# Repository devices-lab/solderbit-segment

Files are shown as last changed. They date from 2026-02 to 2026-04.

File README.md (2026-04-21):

# solder:bit Segment

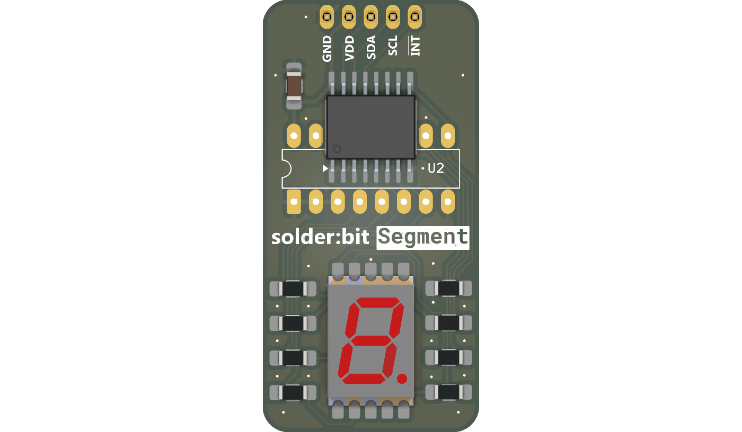
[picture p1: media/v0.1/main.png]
solder:bit Segment A render of the latest solder:bit Segment


The solder:bit Segment is a kit for learning to solder with surface-mount (SMT) components. When assembled, the device can display a single digit on a 7-segment display. It works with any microcontroller that communicates over the [I²C protocol](https://en.wikipedia.org/wiki/I2C).

This soldering kit is designed to accommodate a wide range of soldering abilities. The I/O expander is available in two different packages. The PCF8574AT in the **SO-16** package is smaller and more challenging to solder, while the PCF8574N in the **DIP-16** package is larger and through-hole (THT), making it more accessible for novices. The same printed circuit board (PCB) has footprints for both packages, and you choose which component to solder based on your ability. The device functions identically regardless of which package you use. Note that once you have soldered one package, the footprint for the other will no longer be accessible.

| I/O expander in an SO-16 package (SMT) | I/O expander in a DIP-16 package (THT) |
| --- | --- |
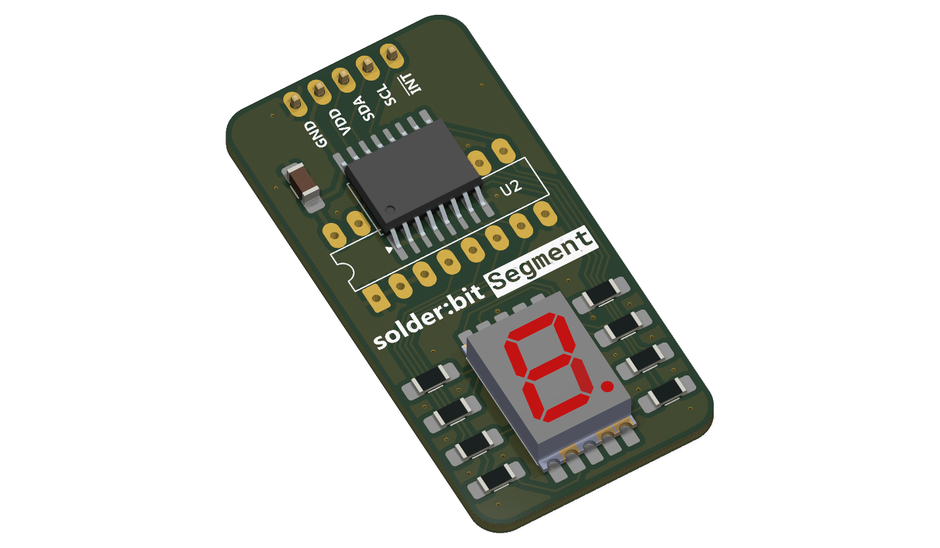
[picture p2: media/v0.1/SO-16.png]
SMT
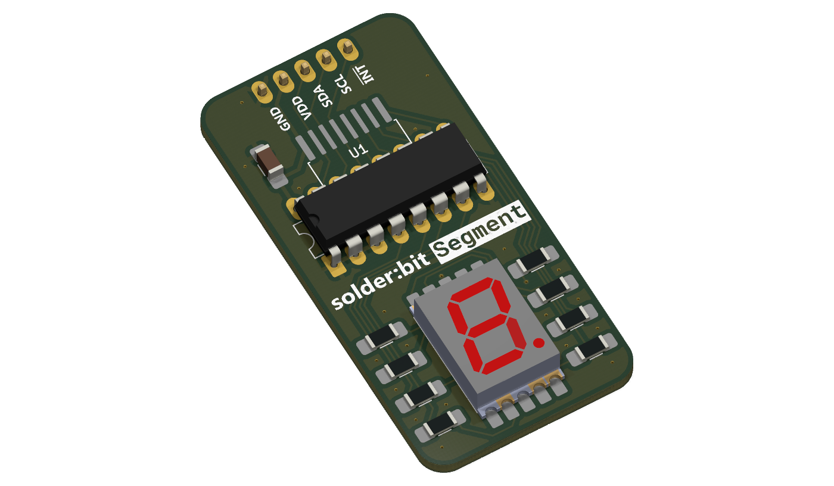
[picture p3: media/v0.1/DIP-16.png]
THT
|  |  |

## Getting started

> [!WARNING]
> This device is a research prototype and is provided as-is. Use it at your own risk. The authors take no responsibility for any damage, injury, or loss arising from its use.

To get started, you will need the following:

1. The printed circuit boards (PCBs), which you will need to have manufactured.
2. All components listed in the bill of materials (BOM).
3. A microcontroller development board, like the BBC micro:bit.
4. All equipment and materials required for soldering.

### Printed circuit boards (PCBs)

The solder:bit Segment fabrication files are open source, so you can order the PCBs yourself!

To fabricate the PCB, use the files in the [gerbers-v0.1](/fabrication/gerbers-v0.1/) folder.

### Components

> [!NOTE]
> Most of these components are sourced from [Onecall (Farnell/CPC)](https://onecall.farnell.com/), but as they are fairly common components, alternatives can be found from other suppliers such as LCSC, DigiKey, and others.

| Reference | Quantity | Part | Package | Onecall order code |
| --- | --- | --- | --- | --- |
| C1 | 1 | 1 µF \* | 1206 | 3188966 |
| DS1 | 1 | VDMO10A0 | SMD, 10mm | 2682705 |
| J1 | 1 | 5-pin header \* | 2.54mm, THT | 3049532 |
| R1–R8 | 8 | 150 Ω \* | 1206 | 9240420 |
| U1 | 1 | PCF8574AT | SO-16 | 2776146 |
| U2 | 1 | PCF8574N | DIP-16 | 3124747 |

_\* Generic component; the order code is provided as a reference, but any equivalent component in the same package can be substituted._

Note that U1 and U2 are alternative packages for the same PCF8574 component — you only need one. You can source both and choose whichever you are more comfortable soldering.

The 7-segment display listed above has orange segments. If you would like other colours, Vishay also offers VDMR10A0 (red) and VDMG10A0 (green). Note that you might need to adjust R1-R8 resistor values to ensure the sinking current doesn't exceed 10 mA on each GPIO pin.

Depending on how you plan to connect the solder:bit Segment to your microcontroller development board, you may also need a breadboard and some jumper cables.

### Development board

You can use a BBC micro:bit to control the solder:bit Segment. Once assembled, attach the device to a breadboard, plug the micro:bit into a [breadboard adaptor](https://kitronik.co.uk/products/5664-microbit-breadboard-breakout-board), and connect it to the breadboard. See the [programming](#programming) section below to see how to wire it up.

> [!CAUTION]
> The device works at a supply voltage (VDD) from 2.5 V to 6 V.

The solder:bit Segment can also be used with other microcontroller development boards such as the [Raspberry Pi Pico](https://www.raspberrypi.com/products/raspberry-pi-pico/) or [Arduino Uno](https://store.arduino.cc/products/arduino-uno-rev3), however we currently only provide programming support for the micro:bit.

See the [programming](#programming) section below for how to write code to control the solder:bit Segment.

### Equipment and materials for soldering

The required equipment will vary depending on your soldering setup and needs, but the following is what you will generally need:

- Safety goggles
- Fume extractor fan
- Soldering iron
- Soldering iron stand
- Brass wool
- Silicone mat
- Solder
- Tweezers
- Solder wick

The following items are optional but useful:

- Blue Tack (for keeping the PCB in place)
- PCB holder/helping hands
- Flux
- Tip cleaner
- Desoldering pump
- Isopropyl alcohol (IPA) and cotton swabs
- Multimeter (for checking continuity in solder joints)

> [!CAUTION]
> To minimise health hazards, we recommend using lead-free and rosin-free solder and flux.

> [!TIP]
> If you are running this as a workshop/event activity, an [HDMI digital microscope](https://www.amazon.co.uk/dp/B09VPPS96M) connected to a display is very useful for streaming a soldering demonstration to the entire room.

> [!TIP]
> Smaller soldering iron tips make it easier to reach tight spaces, but they transfer heat less effectively. We recommend trying out a few different tip sizes and choosing one that works well with your soldering iron.

## Assembly instructions

Coming soon...

## Programming

If you are using a BBC micro:bit, you can program the solder:bit Segment in [MakeCode](https://makecode.microbit.org/) using the [pxt-solderbit-segment](https://github.com/devices-lab/pxt-solderbit-segment) extension.

You can test if your assembled device works by flashing the micro:bit with the [demo file](/demo/microbit-solderbit-segment-demo.hex). Attach the solder:bit Segment to a breadboard, insert the micro:bit into a [breadboard adaptor](https://kitronik.co.uk/products/5664-microbit-breadboard-breakout-board), and plug it into the breadboard. Connect the device to the micro:bit using the following pinout:

| solder:bit Segment | BBC micro:bit |
| --- | --- |
| GND | GND |
| VDD | 3V |
| SDA | P20 |
| SCL | P19 |

See [this image](/demo/wiring_front.jpeg) and [this image](/demo/wiring_back.jpeg) for an example of how to wire it up.

For any other development board, you will need to write the firmware yourself. Refer to the [solder:bit Segment schematic](/reference/solderbit%20Segment%20v0.1%20schematic.pdf), the datasheets for the I/O expanders (both packages), and the 7-segment display datasheet, all of which are available in the [reference](/reference/) folder.

> [!WARNING]
> The two I/O expander packages have different I²C addresses. With the current PCB layout and configuration, the PCF8574AT (SO-16 package) has an I²C address of `0x38`, while the PCF8574N (DIP-16 package) has an address of `0x20`. When writing your own firmware, make sure you are using the correct address for the package you have soldered. The [pxt-solderbit-segment](https://github.com/devices-lab/pxt-solderbit-segment) MakeCode extension handles this for you.

## Project status and contributing

This project is actively maintained. See [CHANGELOG.md](/CHANGELOG.md) for the latest changes.

At this time, external contributions are not being accepted. If you have suggestions or have found an issue, feel free to open a GitHub issue and we will take a look.

## Contact

If you are interested in using solder:bit kits for your classroom, university, conference, or any other workshop or event, feel free to reach out to me @mac-aron or contact [Devices Lab](https://devices-lab.org/contact).

## Acknowledgements

Special thanks to everyone at the [Devices Lab](https://www.devices-lab.org/) for their ongoing support on this project and for their help running soldering workshops.

## License

This project is licensed under the GNU General Public License (GPL), version 3. This license allows you to use, modify, and redistribute the solder:bit Segment and any derivative works, but all such derivatives must also be licensed under the GPL.

The GPL ensures that all modifications and improvements to the solder:bit Segment remain free and open for the public benefit. By using this project, you agree to abide by its terms and conditions.

For more details on the license, please see the [LICENSE](/LICENSE) file included in this repository.

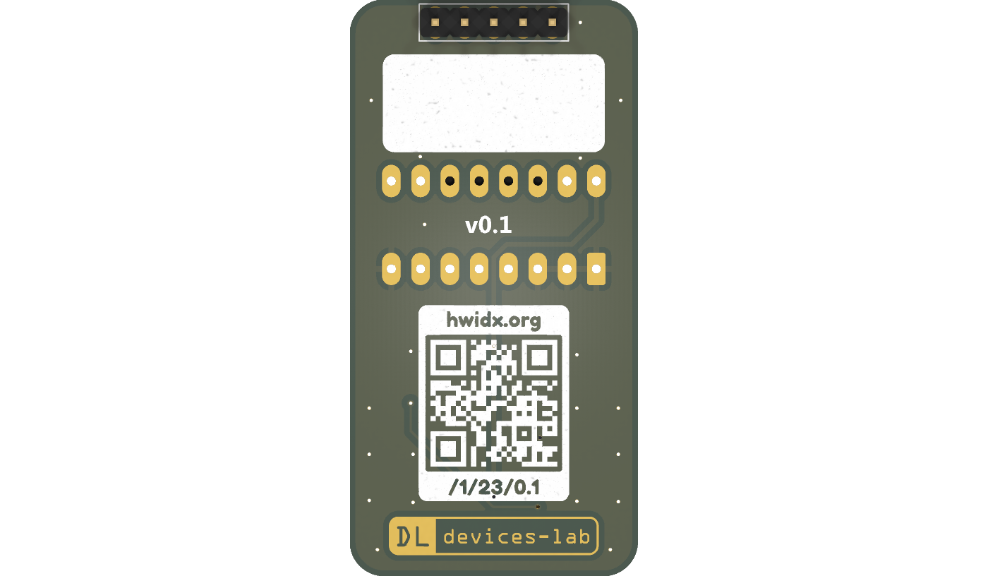
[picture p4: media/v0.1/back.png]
Back of the solder:bit Segment A render of the back of the latest solder:bit Segment


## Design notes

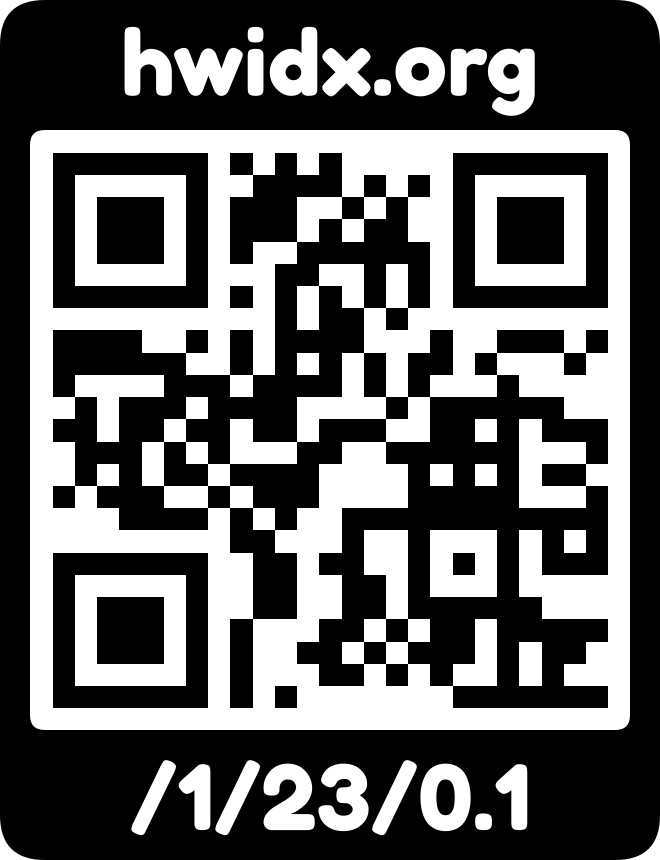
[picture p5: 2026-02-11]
media/v0.1/hwidx.png

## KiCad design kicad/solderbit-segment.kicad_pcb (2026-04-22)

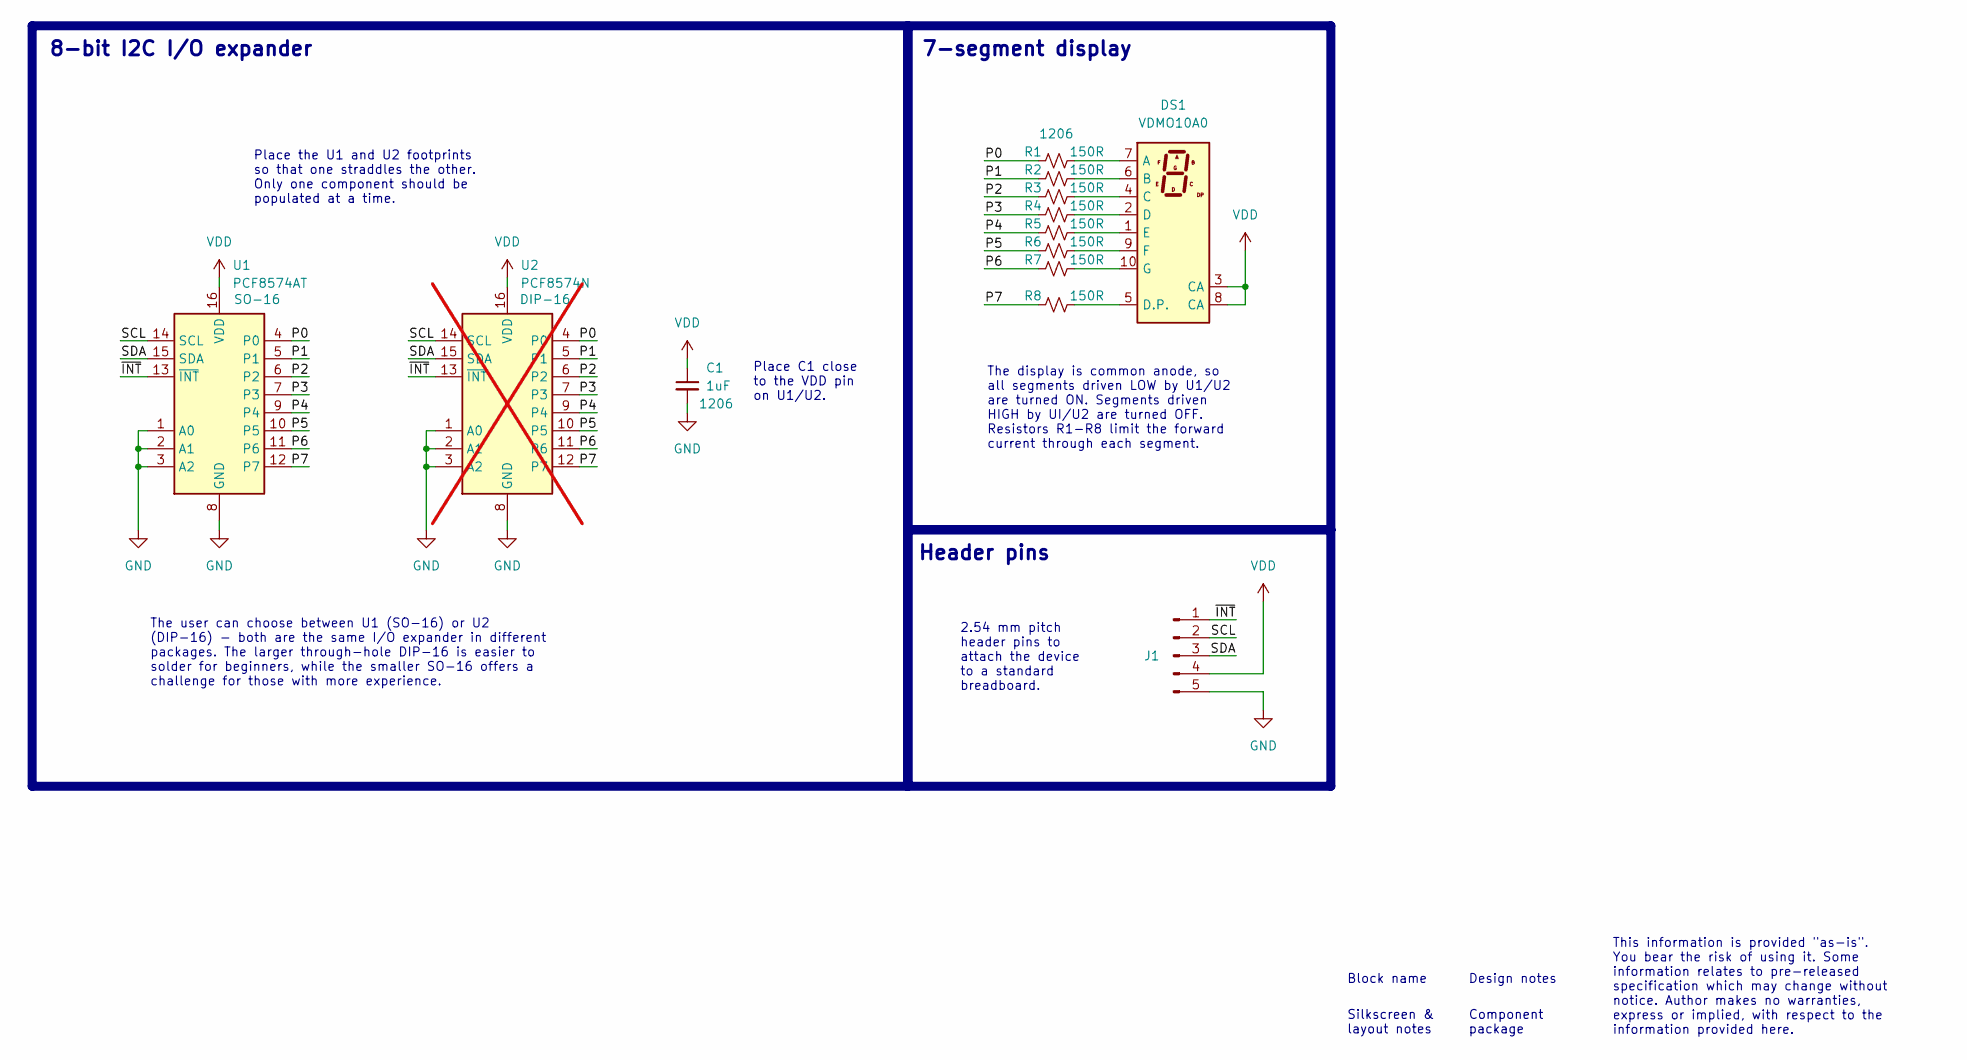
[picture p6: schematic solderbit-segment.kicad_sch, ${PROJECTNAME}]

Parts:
C1: 1uF; C_1206
DS1: VDMO10A0; VDMR10; LCSC Part C2913076
J1: Conn_01x05_Pin; PinHeader_1x05_P2.54mm_Vertical
R1, R2, R3, R4, R5, R6, R7, R8: 150R; R_1206
U1: PCF8574AT; SO-16
U2: PCF8574N; DIP-16; not fitted

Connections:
/P0: R1.1, U1.4 (P0), U2.4 (P0)
/P1: R2.1, U1.5 (P1), U2.5 (P1)
/P2: R3.1, U1.6 (P2), U2.6 (P2)
/P3: R4.1, U1.7 (P3), U2.7 (P3)
/P4: R5.1, U1.9 (P4), U2.9 (P4)
/P5: R6.1, U1.10 (P5), U2.10 (P5)
/P6: R7.1, U1.11 (P6), U2.11 (P6)
/P7: R8.1, U1.12 (P7), U2.12 (P7)
/SCL: J1.2, U1.14 (SCL), U2.14 (SCL)
/SDA: J1.3, U1.15 (SDA), U2.15 (SDA)
/~INT: J1.1, U1.13 (~INT), U2.13 (~INT)
GND: C1.2, J1.5, U1.1 (A0), U1.2 (A1), U1.3 (A2), U1.8 (GND), U2.1 (A0), U2.2 (A1), U2.3 (A2), U2.8 (GND)
unnamed: DS1.7 (A), R1.2
unnamed: DS1.6 (B), R2.2
unnamed: DS1.4 (C), R3.2
unnamed: DS1.2 (D), R4.2
unnamed: DS1.5 (D.P.), R8.2
unnamed: DS1.1 (E), R5.2
unnamed: DS1.9 (F), R6.2
unnamed: DS1.10 (G), R7.2
VDD: C1.1, DS1.3 (CA), DS1.8 (CA), J1.4, U1.16 (VDD), U2.16 (VDD)

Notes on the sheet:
The user can choose between U1 (SO-16) or U2 (DIP-16) - both are the same I/O expander in different packages. The larger through-hole DIP-16 is easier to solder for beginners, while the smaller SO-16 offers a challenge for those with more experience.
Silkscreen & layout notes
Component package
Place the U1 and U2 footprints so that one straddles the other. Only one component should be populated at a time.
2.54 mm pitch header pins to attach the device to a standard breadboard.
Header pins
Block name
This information is provided "as-is". You bear the risk of using it. Some information relates to pre-released specification which may change without notice. Author makes no warranties, express or implied, with respect to the information provided here.
The display is common anode, so all segments driven LOW by U1/U2 are turned ON. Segments driven HIGH by UI/U2 are turned OFF. Resistors R1-R8 limit the forward current through each segment.
Place C1 close to the VDD pin on U1/U2.
7-segment display
8-bit I2C I/O expander
Design notes

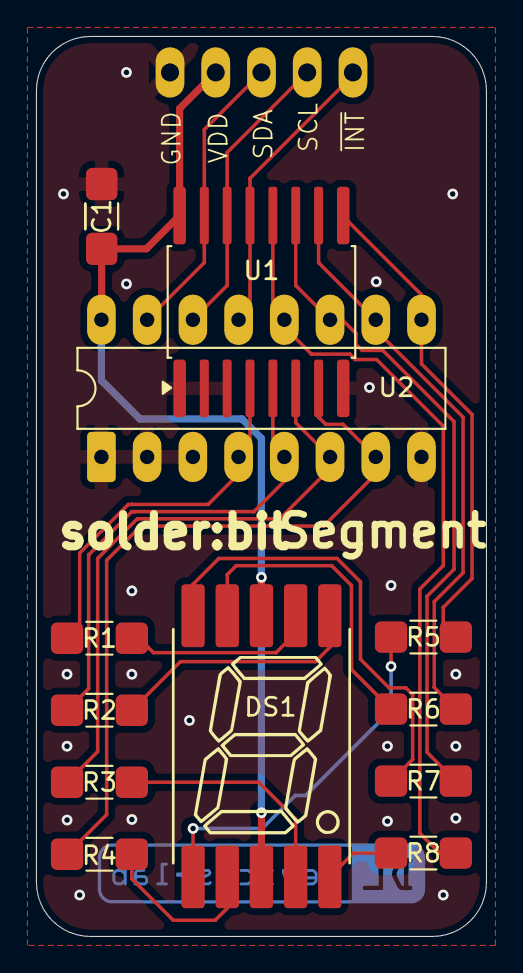
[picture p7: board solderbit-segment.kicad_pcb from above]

Board: 2 copper layers, 25.0 x 50.0 mm, 13 parts (1 on the bottom side), 21 nets.

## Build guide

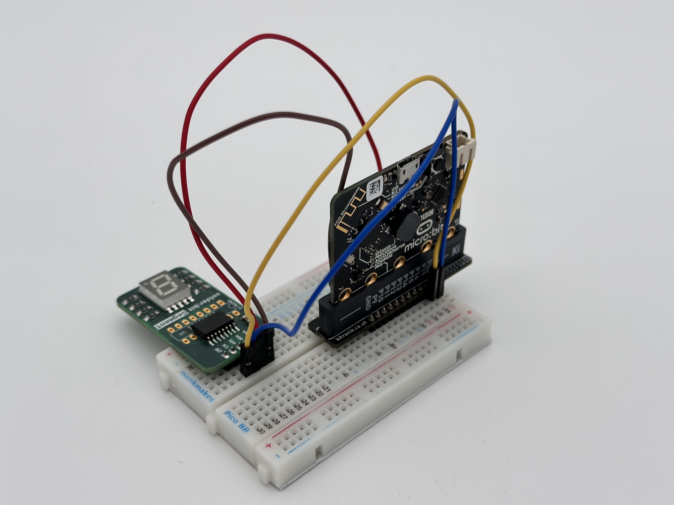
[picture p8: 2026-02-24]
demo/wiring_back.jpeg

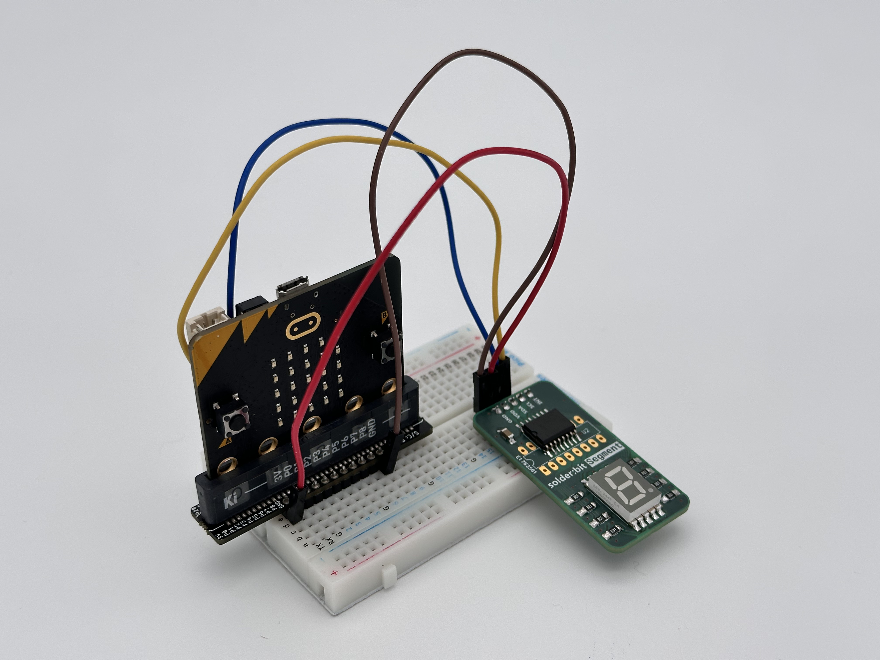
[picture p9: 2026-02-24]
demo/wiring_front.jpeg

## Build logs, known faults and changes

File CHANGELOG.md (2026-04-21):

# Changelog for solder:bit Segment

Each version captures specific changes categorized under "Added", "Changed", "Removed", and "Fixed" to provide an overview of the development progression.

## v0.2

For this version, the plan is to implement the following:

1. Add J1 designator on the silkscreen for the header pins
2. Make the QR code on the back smaller, and consider the new format more in line with Devices Lab
3. Route the address pins on the I/O expanders so that both packages end up with the same I2C address.
4. Update the name of the footprint + name of the package to the correct name: Package_SO:SOIC-16W_7.5x10.3mm_P1.27mm
5. Update other symbols to match the new ones in the solder:bit Segment Shift Edition

## v0.1

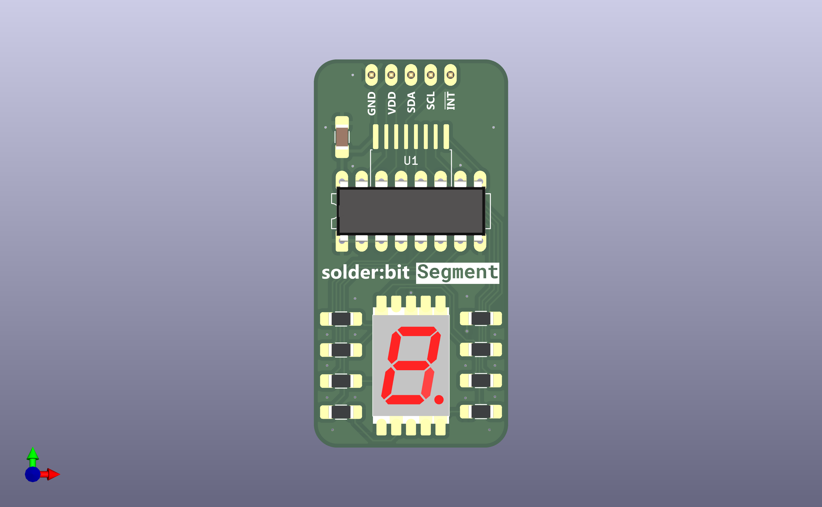
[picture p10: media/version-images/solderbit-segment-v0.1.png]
Device in version 0.1 solder:bit Segment v0.1


### Added

- First version of the PCB

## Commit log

2026-02-11 Second commit
    [solderbit-segment-B_Fab.gbr, solderbit-segment-B_Mask.gbs, solderbit-segment-B_Silkscreen.gbo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]
2026-02-11 Separate SMT version, and THT I/O expander
    [solderbit-segment-B_Cu.gbl, solderbit-segment-B_Fab.gbr, solderbit-segment-B_Mask.gbs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]
2026-02-11 PCB with dual footprints
    [solderbit-segment-B_Cu.gbl, solderbit-segment-B_Fab.gbr, solderbit-segment-B_Mask.gbs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]
2026-02-11 Update README and generate some renders
    [solderbit-segment.kicad_pcb]
2026-02-11 Deleted all KiCad backup files
2026-02-17 Update schematic and cleanup
    [solderbit-segment.kicad_pcb, solderbit-segment.kicad_sch]
2026-02-18 added devices-lab/solderbit-segment-firmware as a submodule
2026-02-18 Fixed the 7-segment display part number
    [solderbit-segment.kicad_pcb, solderbit-segment.kicad_sch]
2026-02-18 Removed initial experiments
    [solderbit-segment-v0.1-SMT.kicad_pcb, solderbit-segment-v0.1-SMT.kicad_sch, solderbit-segment-v0.1-THT.kicad_pcb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]
2026-02-18 Make a copy to archive v0.1
    [solderbit-segment-v0.1.kicad_pcb, solderbit-segment-v0.1.kicad_sch]
2026-02-24 Repo cleanup and library links changes
    [solderbit-segment-B_Cu.gbl, solderbit-segment-B_Fab.gbr, solderbit-segment-B_Mask.gbs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]
2026-02-26 New documentation
    [solderbit-segment-B_Cu.gbl, solderbit-segment-B_Fab.gbr, solderbit-segment-B_Mask.gbs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]
2026-02-26 Updated renders of the packages
    [solderbit-segment.kicad_pcb]
2026-02-26 Added an image of the back to README
    [solderbit-segment.kicad_pcb]
2026-04-21 Update documentation
    [solderbit-segment.kicad_pcb, solderbit-segment.kicad_sch]
2026-04-22 First save with KiCad 10
    [solderbit-segment.kicad_pcb, solderbit-segment.kicad_sch]
2026-04-22 Updated renders with green soldermask
